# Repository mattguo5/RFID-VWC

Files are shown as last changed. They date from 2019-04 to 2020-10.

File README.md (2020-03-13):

# RFID-VWC

The RFID-VWC Github repository serves to document all of the hardware and software implementations for the Oregon State University OPEnS RFID Moisture project.

Directory information:

BOM

    - Contains the most up-to-date BOM of the overall project
  
Code

  - Adafruit_Logging
  
        - Contains the most up-to-date Adafruit STEMMA Soil Moisture firmware code
      
  - Implementation
  
        - Contains the Feather M0 port of firmware for the RFID Sensor
  - src
  
        - Includes all dependencies needed to compile the above .ino files
      
Hardware

    -Contains .brd and .sch files of the RFID-Feather Interface Boards for communication with the Feather M0

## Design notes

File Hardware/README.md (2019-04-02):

This is the .sch and .brd of the interface board for the Sparkfun RFID reader and Feather M0

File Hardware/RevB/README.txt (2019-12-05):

Here contains the board and schematic files for the RevB board Interface Board.

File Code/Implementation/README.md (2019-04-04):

This is the demo code from Arduino IDE that will be used for the demo

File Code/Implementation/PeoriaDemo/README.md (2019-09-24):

Current Arduino version of Peoria Demo, created in June 2019

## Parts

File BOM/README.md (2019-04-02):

Here lies the BOM for the RFID-VWC Project

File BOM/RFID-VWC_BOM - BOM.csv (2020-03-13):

Component | Product ID | Cost per unit | Quantity | Total | Source | Material type | Notes | Development time
High Gain RFID Antenna | ALIEN ALR-8698 | $179.00 | 1 | $179.00 | Atlas RFID | Non-specific
RP-SMA to U.FL Adapter cable | WRL-00662 | $4.95 | 1 | $4.95 | Sparkfun | Non-specific
RFID Reader | SEN-14066 | $224.95 | 1 | $224.95 | Sparkfun | Non-specific
Feather M0 w/ built-in WiFi | 3010 | $34.95 | 1 | $34.95 | Adafruit | Non-specific
Arduino Uno | A000066 | $22.00 | 1 | $22.00 | Arduino | Non-specifc
Neopixel RGB LED | 1312 | $7.95 | 1 | $7.95 | Adafruit | Non-specific | Sold as pack of 4
SmartTrac Dogbone RFID Tag | 3004837 | $0.12 | 3 | $0.36 | Atlas RFID | Non-specific
Attachment hardware | M4 x 0.7 screws |  | 4
3D printed enclosure | N/A |  | 1
10,000 mAh Power Bank | AK-A1263011 | $31.99 | 1 | $31.99 | Amazon | Non-specific
Adafruit Power Relay Featherwing | 3191 | $9.95 | 1 | $9.95 | Adafruit | Non-specific
 |  |  | Total: | $516.10
Soil Moisture Loggers x 3
Feather M0 Proto |  |  | 1
Hypnos Board |  |  | 1 |  |  |  | Talk to Bao
Decagon PCB, 3.5mm jack soil moisture sensor input |  |  | 1 |  |  |  | Talk to Bao
3.5mm waterproof jacks |  |  | 6
DF Robot Soil moisture Sensors |  |  | 6
SD Card 4Gig or less, micro
Headers
Weatherproof box |  |  |  |  | Adafruit

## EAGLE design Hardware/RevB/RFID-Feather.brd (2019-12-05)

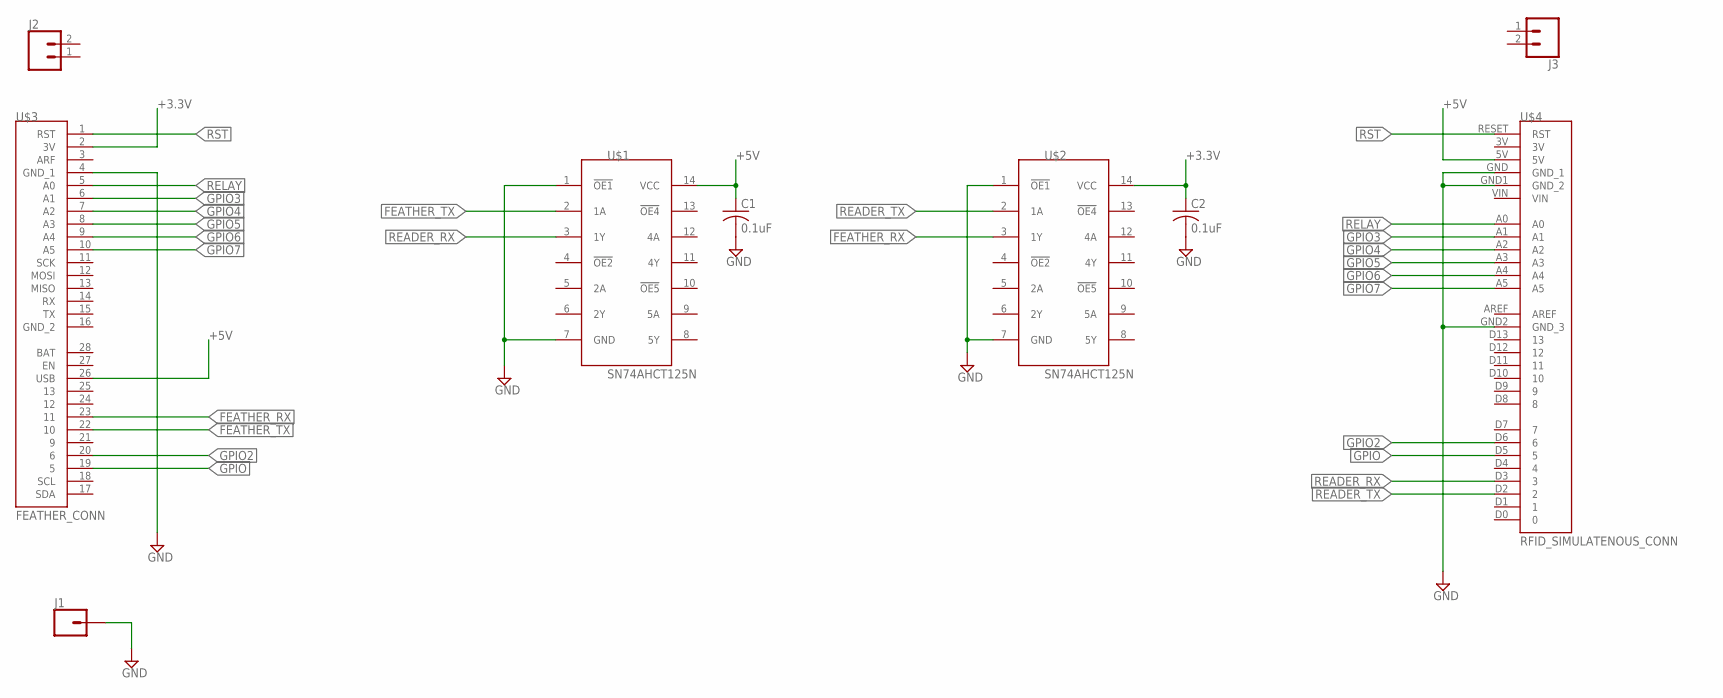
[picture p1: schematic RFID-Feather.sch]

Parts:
C1, C2: 0.1uF; C0805K
J1: CONN_01PTH_2MM; 1X01_2MM
J2, J3: CONN_02; 1X02
U$1, U$2: SN74AHCT125N; DIP254P762X508-14P
U$3: FEATHER_CONN; FEATHERWING
U$4: RFID_SIMULATENOUS_CONN; ARDUINO

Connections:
+3.3V: C2.1, U$2.14 (VCC), U$3.2 (3V)
+5V: C1.1, U$1.14 (VCC), U$3.26 (USB), U$4.5V
FEATHER_RX: U$2.3 (1Y), U$3.23 (11)
FEATHER_TX: U$1.2 (1A), U$3.22 (10)
GND: C1.2, C2.2, J1.1, U$1.1 (!OE1), U$1.7 (GND), U$2.1 (!OE1), U$2.7 (GND), U$3.4 (GND_1), U$4.GND (GND_1), U$4.GND1 (GND_2), U$4.GND2 (GND_3)
GPIO: U$3.19 (5), U$4.D5 (5)
GPIO2: U$3.20 (6), U$4.D6 (6)
GPIO3: U$3.6 (A1), U$4.A1
GPIO4: U$3.7 (A2), U$4.A2
GPIO5: U$3.8 (A3), U$4.A3
GPIO6: U$3.9 (A4), U$4.A4
GPIO7: U$3.10 (A5), U$4.A5
READER_RX: U$1.3 (1Y), U$4.D3 (3)
READER_TX: U$2.2 (1A), U$4.D2 (2)
RELAY: U$3.5 (A0), U$4.A0
RST: U$3.1 (RST), U$4.RESET (RST)

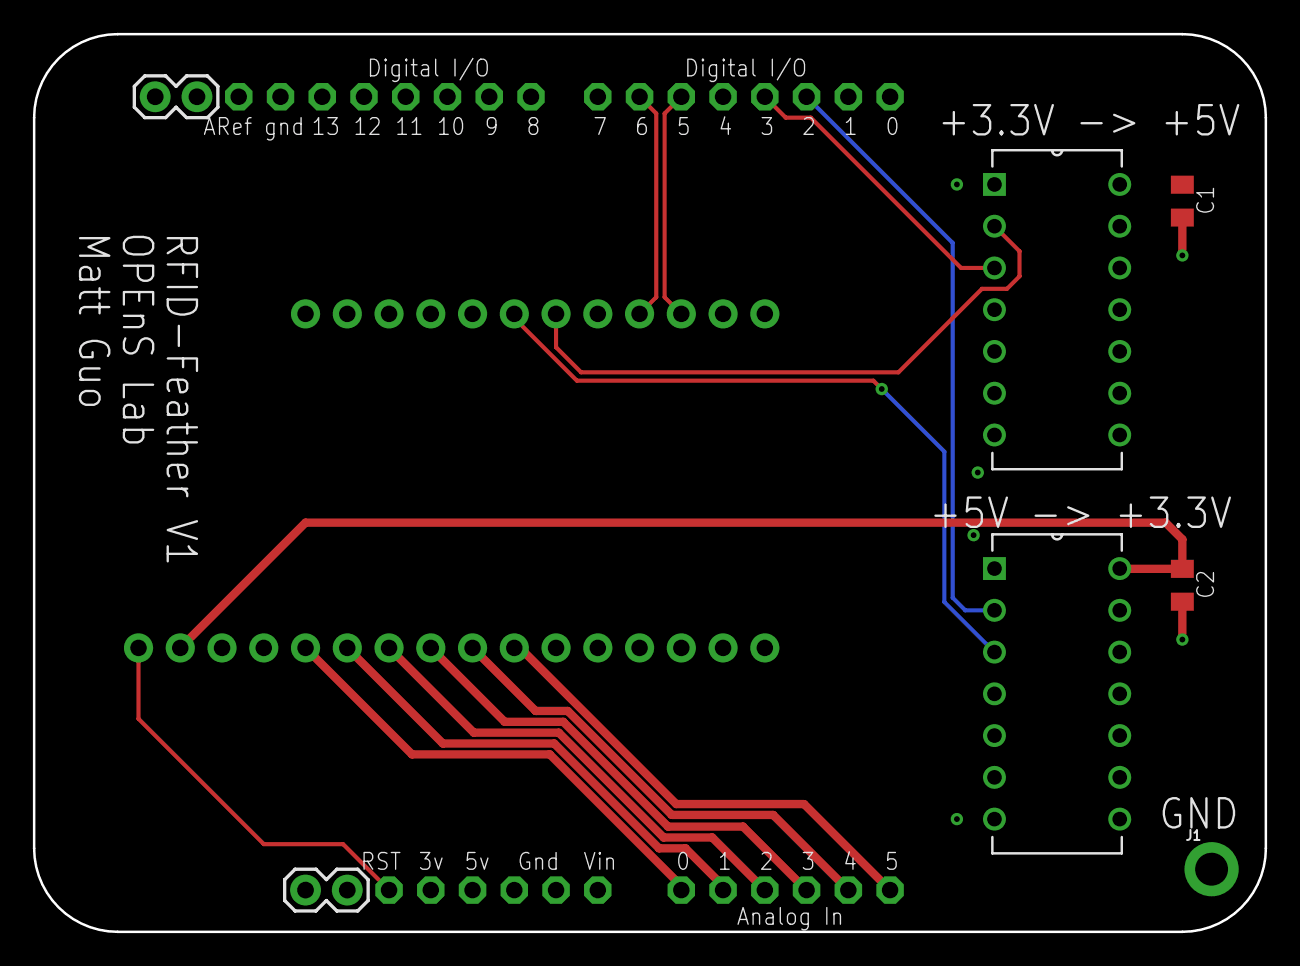
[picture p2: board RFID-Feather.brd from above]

Board: 2 copper layers, 74.9 x 54.6 mm, 9 parts (0 on the bottom side), 16 nets.

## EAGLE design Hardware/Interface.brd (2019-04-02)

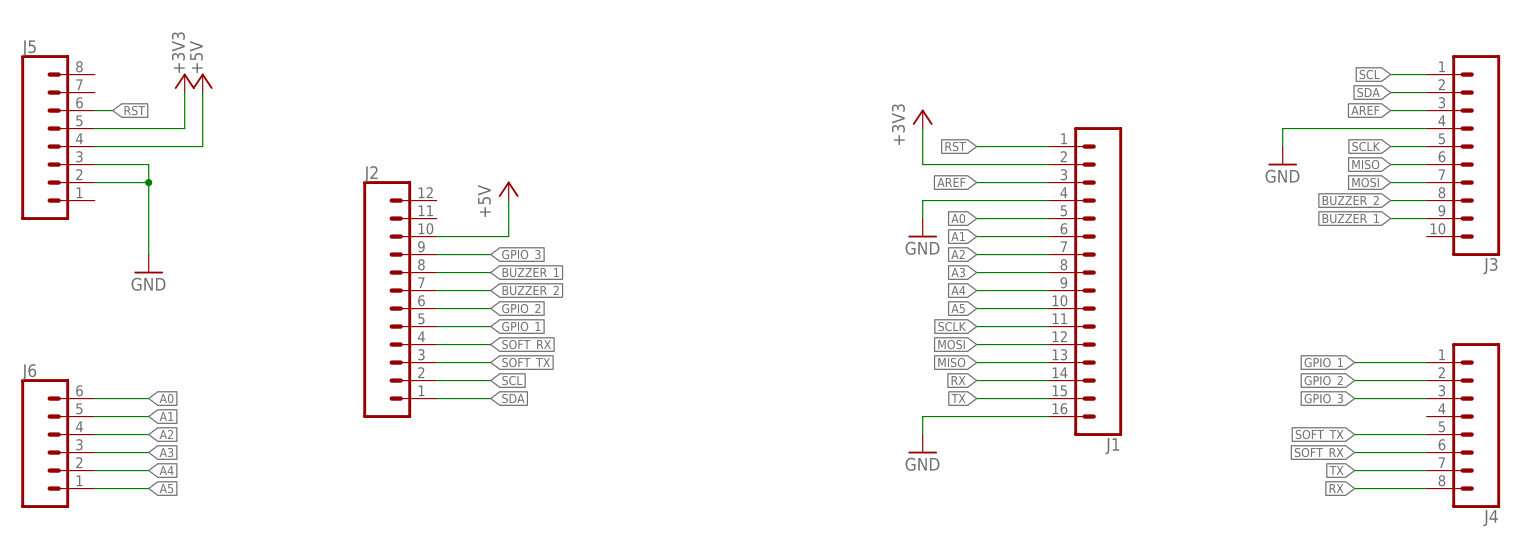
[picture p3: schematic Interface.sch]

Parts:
J1: CONN_16; 1X16
J2: CONN_12; 1X12
J3: CONN_10"; 1X10
J4, J5: CONN_08"; 1X08
J6: CONN_06SILK_FEMALE_PTH; 1X06

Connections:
+3V3: J1.2, J5.5
+5V: J2.10, J5.4
A0: J1.5, J6.6
A1: J1.6, J6.5
A2: J1.7, J6.4
A3: J1.8, J6.3
A4: J1.9, J6.2
A5: J1.10, J6.1
AREF: J1.3, J3.3
BUZZER_1: J2.8, J3.9
BUZZER_2: J2.7, J3.8
GND: J1.4, J1.16, J3.4, J5.2, J5.3
GPIO_1: J2.5, J4.1
GPIO_2: J2.6, J4.2
GPIO_3: J2.9, J4.3
MISO: J1.13, J3.6
MOSI: J1.12, J3.7
RST: J1.1, J5.6
RX: J1.14, J4.8
SCL: J2.2, J3.1
SCLK: J1.11, J3.5
SDA: J2.1, J3.2
SOFT_RX: J2.4, J4.6
SOFT_TX: J2.3, J4.5
TX: J1.15, J4.7

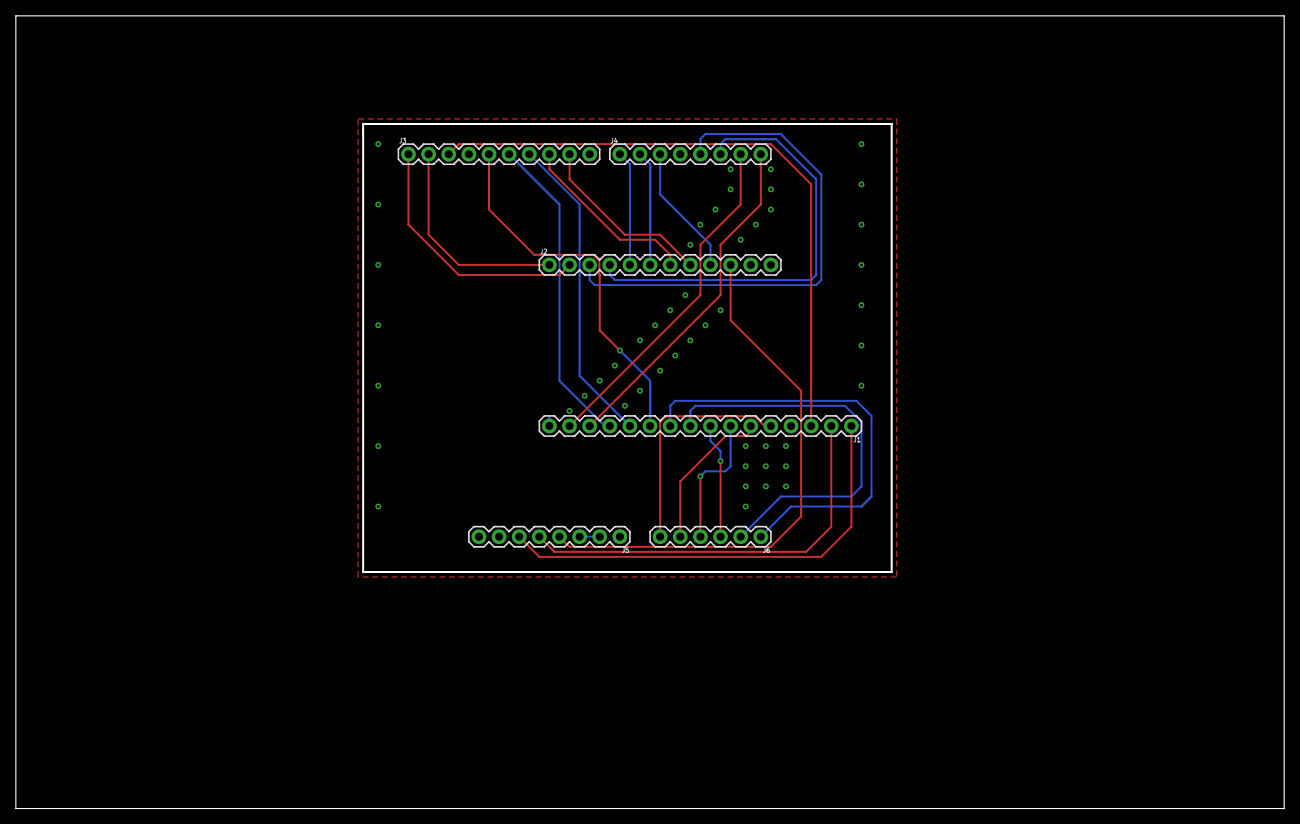
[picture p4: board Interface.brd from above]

Board: 2 copper layers, 160.0 x 100.0 mm, 6 parts (0 on the bottom side), 25 nets.

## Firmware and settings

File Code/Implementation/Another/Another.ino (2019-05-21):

/*
  Reading multiple RFID tags, simultaneously!
  By: Nathan Seidle @ SparkFun Electronics
  Date: October 3rd, 2016
  https://github.com/sparkfun/Simultaneous_RFID_Tag_Reader

  Constantly reads and outputs any tags heard

  If using the Simultaneous RFID Tag Reader (SRTR) shield, make sure the serial slide
  switch is in the 'SW-UART' position
*/

#include <Adafruit_NeoPixel.h>
#ifdef __AVR__
  #include <avr/power.h>
#endif

// Which pin on the Arduino is connected to the NeoPixels?
// On a Trinket or Gemma we suggest changing this to 1
#define PIN            6

// How many NeoPixels are attached to the Arduino?
#define NUMPIXELS      1

//What is the Threshold for dry?
#define THRESHOLD_DRY     15

//What is the Threshold for wet?
#define THRESHOLD_MEDIUM     10

//What length is the desired EPC array?
#define EPC_LENGTH    100

//How much to flash white during time a disconnect?
#define FLASHAMOUNT   10

// When we setup the NeoPixel library, we tell it how many pixels, and which pin to use to send signals.
// Note that for older NeoPixel strips you might need to change the third parameter--see the strandtest
// example for more information on possible values.
Adafruit_NeoPixel pixel = Adafruit_NeoPixel(NUMPIXELS, PIN, NEO_GRB + NEO_KHZ800);

int delayval = 500; // delay for half a second

#include <SoftwareSerial.h> //Used for transmitting to the device

SoftwareSerial softSerial(2, 3); //RX, TX

#include "SparkFun_UHF_RFID_Reader.h" //Library for controlling the M6E Nano module
RFID nano; //Create instance

void setup()
{

  pixel.begin(); // This initializes the NeoPixel library.
  pixel.setPixelColor(0, 0, 0, 0);
  pixel.show();
  
  Serial.begin(115200);
  while (!Serial); //Wait for the serial port to come online

  if (setupNano(38400) == false) //Configure nano to run at 38400bps
  {
    Serial.println(F("Module failed to respond. Please check wiring."));
    while (1); //Freeze!
  }

  nano.setRegion(REGION_NORTHAMERICA); //Set to North America

  nano.setReadPower(1300); //5.00 dBm. Higher values may caues USB port to brown out
  //Max Read TX Power is 27.00 dBm and may cause temperature-limit throttling

  //Serial.println(F("Press a key to begin scanning for tags."));
  //while (!Serial.available()); //Wait for user to send a character
  //Serial.read(); //Throw away the user's character

  nano.startReading(); //Begin scanning for tags
}

void loop()
{
  if (nano.check() == true) //Check to see if any new data has come in from module
  {
    byte responseType = nano.parseResponse(); //Break response into tag ID, RSSI, frequency, and timestamp

    if (responseType == RESPONSE_IS_KEEPALIVE)
    {
      Serial.println(F("Scanning"));
    }
    else if (responseType == RESPONSE_IS_TAGFOUND)
    {
      //If we have a full record we can pull out the fun bits
      int rssi = nano.getTagRSSINew(); //Get the RSSI for this tag read

      long freq = nano.getTagFreqNew(); //Get the frequency this tag was detected at


      long moisture = nano.getMoistureData();
      //long timeStamp = nano.getTagTimestamp(); //Get the time this was read, (ms) since last keep-alive message

    
      byte tagEPCBytes = nano.getTagEPCBytesNew(); //Get the number of bytes of EPC from response

      if(freq < 1000000 && nano.getAntennaeIDNew() == 17){


          if(moisture >= THRESHOLD_DRY) 
      {
        pixel.setPixelColor(0, 150, 0, 0); // Moderately bright red color.
        pixel.show(); // This sends the updated pixel color to the hardware.
      }
      else if(moisture >= THRESHOLD_MEDIUM)
      {
        pixel.setPixelColor(0, 0, 150, 0); // Moderately bright green color.
        pixel.show(); // This sends the updated pixel color to the hardware.  
      }
      else
      {
        pixel.setPixelColor(0, 0, 0, 150); //Moderately bright blue color.
        pixel.show(); //This sends the updated pixel color to the hardware.
      }


         Serial.print(F(" rssi["));
        Serial.print(rssi);
        Serial.print(F("]"));

        Serial.print(F(" freq["));
        Serial.print(freq);
        Serial.print(F("]"));

        Serial.print(F(" Moisture["));
        Serial.print(moisture);
        Serial.print(F("]"));

      //Print EPC bytes, this is a subsection of bytes from the response/msg array
        Serial.print(F(" epc["));
        for (byte x = 0 ; x < tagEPCBytes ; x++)
        {
         if (nano.msg[31 + x] < 0x10) Serial.print(F("0")); //Pretty print
          Serial.print(nano.msg[37 + x], HEX);
          Serial.print(F(" "));
        }
        Serial.print(F("]"));

        Serial.println();
      }

     
    }
    else if (responseType == ERROR_CORRUPT_RESPONSE)
    {
      Serial.println("Bad CRC");
    }
    else
    {
      //Unknown response
      Serial.println("Unknown error");
    }
  }
}

//Gracefully handles a reader that is already configured and already reading continuously
//Because Stream does not have a .begin() we have to do this outside the library
boolean setupNano(long baudRate)
{
  nano.begin(softSerial); //Tell the library to communicate over software serial port

  //Test to see if we are already connected to a module
  //This would be the case if the Arduino has been reprogrammed and the module has stayed powered
  softSerial.begin(baudRate); //For this test, assume module is already at our desired baud rate
  while(!softSerial); //Wait for port to open

  //About 200ms from power on the module will send its firmware version at 115200. We need to ignore this.
  while(softSerial.available()) softSerial.read();
  
  nano.getVersion();

  if (nano.msg[0] == ERROR_WRONG_OPCODE_RESPONSE)
  {
    //This happens if the baud rate is correct but the module is doing a ccontinuous read
    nano.stopReading();

    Serial.println(F("Module continuously reading. Asking it to stop..."));

    delay(1500);
  }
  else
  {
    //The module did not respond so assume it's just been powered on and communicating at 115200bps
    softSerial.begin(115200); //Start software serial at 115200

    nano.setBaud(baudRate); //Tell the module to go to the chosen baud rate. Ignore the response msg

    softSerial.begin(baudRate); //Start the software serial port, this time at user's chosen baud rate
  }

  //Test the connection
  nano.getVersion();
  if (nano.msg[0] != ALL_GOOD) return (false); //Something is not right

  //The M6E has these settings no matter what
  nano.setTagProtocol(); //Set protocol to GEN2

  nano.setAntennaPort(); //Set TX/RX antenna ports to 1

  return (true); //We are ready to rock
}

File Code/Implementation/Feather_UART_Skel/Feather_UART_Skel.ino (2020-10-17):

/*
  Skeleton Code for UART SERCOM on the Feather M0
*/

//TODO: clean up relay_switch function so that toggling is not necessary for each iteration
//		  of state machine.
//TODO: test fertigate functionality

//#include <Loom.h>
#include "wiring_private.h"           // pinPeripheral() function


//const char* json_config = 
//#include "config.h"
//;
//// Set enabled modules
//LoomFactory<
//  Enable::Internet::Disabled,
//  Enable::Sensors::Enabled,
//  Enable::Radios::Disabled,
//  Enable::Actuators::Disabled,
//  Enable::Max::Disabled
//> ModuleFactory{};
//
//LoomManager Loom{ &ModuleFactory };


#define UART_TX 10
#define UART_RX 11


//Tx ---> 10
//Rx ---> 11
Uart newSerial(&sercom1, UART_RX, UART_TX, SERCOM_RX_PAD_0, UART_TX_PAD_2 );

void SERCOM1_Handler() {
   newSerial.IrqHandler();
}

void setup()
{

	Serial.begin(115200);
	//while (!Serial); //Wait for the serial port to come online
	
	newSerial.begin(115200);
	
	pinPeripheral(10, PIO_SERCOM);
	pinPeripheral(11, PIO_SERCOM);
	
	while(!newSerial);
	
	delay(1000);
}


//main loop of the program, calls the state machine for individual
//tags upon successive tag responses
void loop()
{
	while(newSerial.available()) newSerial.read();
	delay(100);
}

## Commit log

2019-05-21 Arduino Demo
2020-03-13 Pushed Most Recent Adafruit Soil Sensor Code
2020-03-13 Added Logger-Box BOM
    [RFID-VWC_BOM - BOM.csv]

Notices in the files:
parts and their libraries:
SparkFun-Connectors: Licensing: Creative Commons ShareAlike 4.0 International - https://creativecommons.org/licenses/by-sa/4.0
